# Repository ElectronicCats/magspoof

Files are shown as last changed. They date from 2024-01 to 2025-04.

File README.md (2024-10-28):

# MagSpoof By Electronic Cats
  
<a href="https://github.com/ElectronicCats/magspoof/wiki">
  <p align="center">
    
  </p>

<p align=center>
<a href="https://electroniccats.com/store/magspoof-v5/">
  
</a>
<a href="https://github.com/ElectronicCats/magspoof/wiki">
  
</a>
</p>

<p align=center>
Also available at distributors:
</p>
<p align=center>
<a href="https://labs.ksec.co.uk/product-category/electronic-cat/">

</a>
</p>

# What is MagSpoof?

**MagSpoof by Electronic Cats** is a device that can spoof/emulate any magnetic stripe or credit card. It can work "wirelessly", even on **standard magstripe/credit card readers**, by generating a strong electromagnetic field that emulates a traditional magnetic stripe card.

* Allows you to store all of your credit cards and magstripes in one device
* Works on traditional magstripe readers **wirelessly** (no NFC/RFID required)
* Can **disable** Chip-and-PIN (code not included)
* Correctly **predicts** Amex credit card numbers + expirations from previous card number (code not included)
* Supports all three magnetic stripe tracks, and even supports Track 1+2 simultaneously
* Easy to build using Arduino or other common parts

MagSpoof can be used as a traditional credit card and simply store all of your credit cards (and with modification, can technically disable chip requirements) in various impressive and exciting form factors, or can be used for security research in any area that would traditionally require a magstripe, such as readers for credit cards, drivers licenses, hotel room keys, automated parking lot tickets, etc.

**Note**: The Chip-and-PIN and Amex information is **not** implemented and using MagSpoof requires you to have/own the magstripes that you wish to emulate. Simply having a credit card number and expiration is not enough to perform transactions. MagSpoof **does** allow you to perform research in other areas of magstripes, microcontrollers, and electromagnetism, as well as learn about and create your own devices similar to other existing, commercial technologies such as <a href="http://www.samsung.com/us/support/answer/ANS00043865/997410383/">Samsung MST</a> and <a href="https://onlycoin.com/">Coin</a>.</p>

### ⚠️ Disclaimer ⚠️
MagSpoof is a wireless penetration testing tool intended solely for use in authorized security audits, where such usage is permitted by applicable laws and regulations. Before utilizing this tool, it is crucial to ensure compliance with all relevant legal requirements and obtain appropriate permissions from the relevant authorities.

It is essential to notice that the board does not provide any means or authorization to utilize credit cards or engage in any financial transactions that are not legally authorized. Electronic Cats holds no responsibility for any unauthorized use of the tool or any resulting damages.

-----

# Based in work of Samy Kamkar

**Point of Contact:** [@SamyKamkar](https://twitter.com/samykamkar)

You can see more of my projects at <http://samy.pl> or contact me at <code@samy.pl>.

------

## How to contribute 
 Contributions are welcome! 

Please read the document  [**Contribution Manual**](https://github.com/ElectronicCats/electroniccats-cla/blob/main/electroniccats-contribution-manual.md)  which will show you how to contribute your changes to the project.

✨ Thanks to all our [contributors](https://github.com/ElectronicCats/magspoof/graphs/contributors)! ✨

See  [**_Electronic Cats CLA_**](https://github.com/ElectronicCats/electroniccats-cla/blob/main/electroniccats-cla.md) for more information.

See the [**community code of conduct**](https://github.com/ElectronicCats/electroniccats-cla/blob/main/electroniccats-community-code-of-conduct.md)   for a vision of the community we want to build and what we expect from it.

### Maintainer

Electronic Cats invests time and resources in providing this open-source design design, please support Electronic Cats and open-source hardware by purchasing products from Electronic Cats!

<a href="https://github.com/sponsors/ElectronicCats">
  
</a>

# License

<a>
  
</a>

Electronic Cats invests time and resources in providing this open-source design. Please support Electronic Cats and open-source hardware by purchasing products from Electronic Cats!

Designed by Electronic Cats.

Firmware released under an GNU AGPL v3.0 license. See the LICENSE file for more information.

Hardware released under an CERN Open Hardware Licence v1.2. See the LICENSE_HARDWARE file for more information.

Electronic Cats is a registered trademark, please do not use if you sell these PCBs.

30 Octuber 2019

------

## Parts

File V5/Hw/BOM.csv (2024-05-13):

Reference | Value | Datasheet | Footprint | Qty | DNP | LCSC# | Proveedor | manf#
BT1 | Battery_Cell | ~ | Connector_PinHeader_2.54mm:PinHeader_1x02_P2.54mm_Vertical | 1 | DNP |  |  | -
C1,C2 | 0.1uF | https://datasheet.lcsc.com/lcsc/1810101813_YAGEO-CC0805KRX7R9BB104_C49678.pdf | Capacitor_SMD:C_0402_1005Metric | 2 |  | C2171572 | LCSC | GRM022R61A104ME01L
C3,C4,C17,C18 | 10uF | ~https://datasheet.lcsc.com/lcsc/1811021421_Samsung-Electro-Mechanics-CL10A106MP8NNNC_C85713.pdf | Capacitor_SMD:C_0402_1005Metric | 4 |  | C315248 | LCSC | CL05A106MP5NUNC
D1 | MBR120 | http://www.onsemi.com/pub_link/Collateral/MBR340-D.PDF | Diode_SMD:D_SOD-123F | 1 |  | C130880 | LCSC | MBR120LSF
D3 | Status | https://www.mouser.mx/datasheet/2/445/150080VS75000-1714385.pdf | LED_SMD:LED_0805_2012Metric_Pad1.15x1.40mm_HandSolder | 1 |  | C205442 | LCSC | 150080GS75000
D4 | CHG | https://www.mouser.mx/datasheet/2/445/150080RS75000-1714740.pdf | LED_SMD:LED_0805_2012Metric_Pad1.15x1.40mm_HandSolder | 1 |  | C130114 | LCSC | D-R080508L3-KS2
F1 | 0.5A | https://datasheet.lcsc.com/lcsc/1809211126_Shenzhen-JDT-Fuse-JFC0603-0500FS_C136327.pdf | Fuse:Fuse_0603_1608Metric | 1 |  | C2838887 | LCSC | 0603FA-R500
H1,H2,H3,H4 | MountingHole | ~ | MountingHole:MountingHole_2.2mm_M2_DIN965_Pad | 4 | DNP
J1 | SWD | ~ | Connector_PinHeader_2.54mm:PinHeader_1x04_P2.54mm_Vertical | 1 | DNP
J2 | SWD | ~ | Connector_PinHeader_2.54mm:PinHeader_1x04_P2.54mm_Vertical | 1 |  | C6332197 | LCSC | HB-PH3-25414PB2GOP
JP1 | boot | ~ | Connector_PinHeader_2.54mm:PinHeader_1x02_P2.54mm_Vertical | 1 |  | C492401 | LCSC | PZ254V-11-02P
L4 | 30t_30mm |  | magspoof:Coil_30t_30mm_0.2_0.2_0.6_0.3 | 1 | DNP
P1 | USB_C_Plug_USB2.0 | https://www.usb.org/sites/default/files/documents/usb_type-c.zip | magspoof:C393939 | 1 |  | C393939 | LCSC | TYPE-C16PIN
Q1 | DMG3415U-7 | https://www.mouser.mx/datasheet/2/115/ds31735-64958.pdf | Package_TO_SOT_SMD:SOT-23 | 1 |  | C96616 | LCSC | DMG3415UQ-7
R1 | 20K | https://www.mouser.mx/datasheet/2/54/cr-1858361.pdf | Resistor_SMD:R_0402_1005Metric | 1 |  | C2759509 | LCSC | ERJ-H2RD2002X
R2,R3,R9 | 5.1k | https://datasheet.lcsc.com/lcsc/1810170519_PANASONIC-ERJ3RBD5101V_C191782.pdf | Resistor_SMD:R_0402_1005Metric | 3 |  | C317922 | LCSC | AR02BTC5101
R7 | 180R | https://www.mouser.mx/datasheet/2/219/RK73B-1825463.pdf | Resistor_SMD:R_0402_1005Metric | 1 |  | C138045 | LCSC | ERJ-2RKF1800X
R10 | 470 | https://www.mouser.mx/datasheet/2/447/PYu_RC_Group_51_RoHS_L_11-1984063.pdf | Resistor_SMD:R_0402_1005Metric | 1 |  | C114877 | LCSC | RC0402FR-07470RL
R11 | 100K | https://datasheet.lcsc.com/lcsc/1811151133_Walsin-Tech-Corp-WR06X104JTL_C163843.pdf | Resistor_SMD:R_0402_1005Metric | 1 |  | C192169 | LCSC | ERJ-2RKF1003X
SW1 | ON | https://datasheet.lcsc.com/lcsc/1808041445_ALPSALPINE-SSSS811101_C109335.pdf | Library:SW-SMD_SSSS811101 | 1 |  | C109335 | LCSC | SSSS811101
SW3 | S1 | https://datasheet.lcsc.com/lcsc/2205161616_E-Switch-TL3342F450QG_C2886897.pdf | Button_Switch_SMD:SW_SPST_TL3342 | 1 |  | C318889 | LCSC | TL3342F450QG
SW4 | SOURCE MAG | https://datasheet.lcsc.com/lcsc/1808041445_ALPSALPINE-SSSS811101_C109335.pdf | Library:SW-SMD_SSSS811101 | 1 |  | C109335 | LCSC | SSSS811101
SW5 | RESET | https://www.mouser.mx/datasheet/2/140/TL3342-2065746.pdf | Button_Switch_SMD:SW_SPST_TL3342 | 1 |  | C318889 | LCSC | TL3342F450QG
U1 | CH552G | https://datasheet.lcsc.com/lcsc/2008191734_WCH-Jiangsu-Qin-Heng-CH552G_C111292.pdf | Package_SO:SOP-16_4.55x10.3mm_P1.27mm | 1 |  | C111292 | LCSC | CH552G
U2 | AP2112K-3.3 | https://www.diodes.com/assets/Datasheets/AP2112.pdf | Package_TO_SOT_SMD:SOT-23-5 | 1 |  | C47773 | LCSC | RT9013-33GB
U3 | TC4424 | https://www.mouser.mx/datasheet/2/268/21998b-53545.pdf | Package_SO:SOIC-8_3.9x4.9mm_P1.27mm | 1 |  | C44150 | LCSC | TC4424AVOA713
U5 | MCP73831 | http://ww1.microchip.com/downloads/en/DeviceDoc/20001984g.pdf | Package_TO_SOT_SMD:SOT-23-5 | 1 |  | C424093 | LCSC | MCP73831T-2ACI/OT

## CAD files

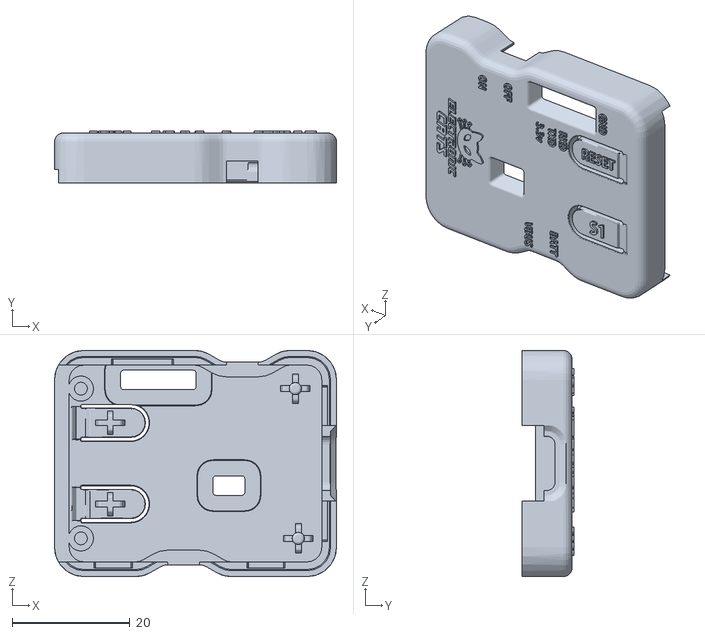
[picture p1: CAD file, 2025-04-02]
V5/Case/CS3-PART A-MAGSPOOF V5-CASE.stl
48.0 x 8.80 x 38.5

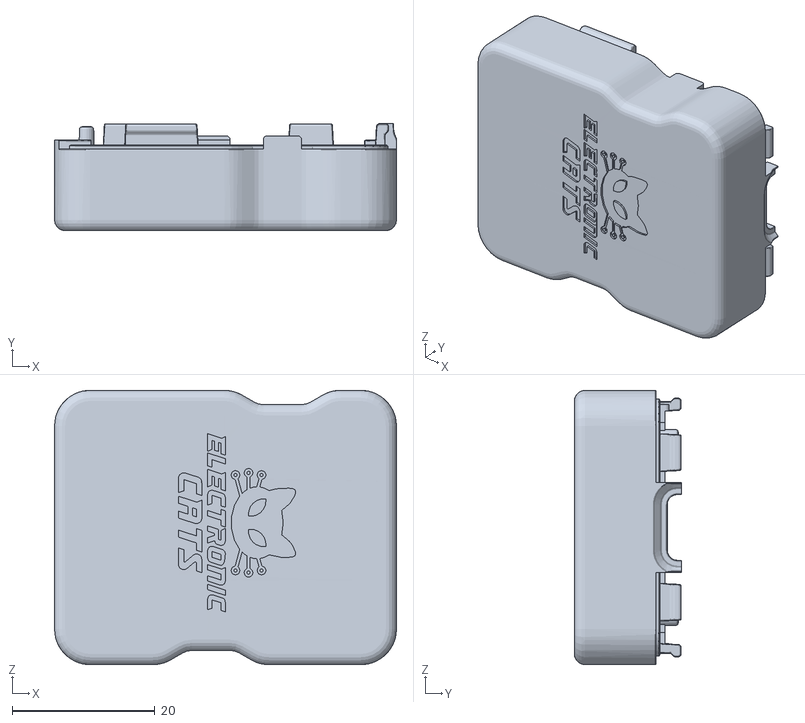
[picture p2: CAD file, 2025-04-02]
V5/Case/CS3-PART B-MAGSPOOF V5-CASE.stl
48.0 x 15.1 x 38.5

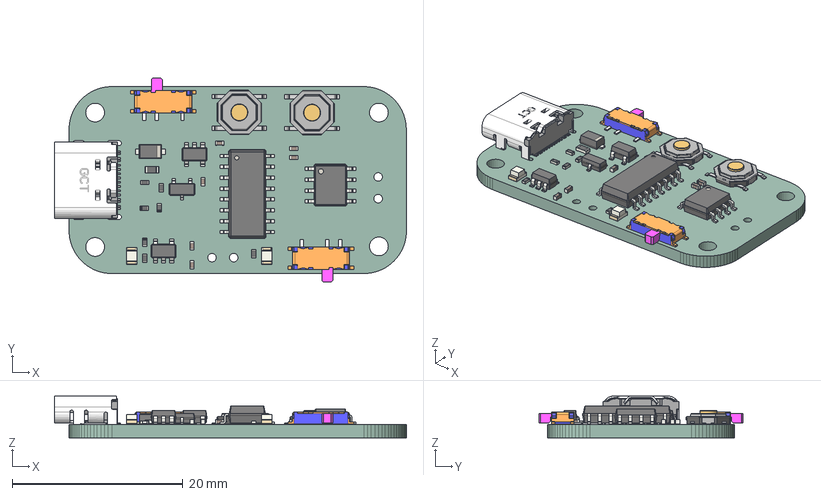
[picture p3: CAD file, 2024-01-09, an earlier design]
V4/Hw/Magspoof_V4.step
41.2 x 23.9 x 4.91 mm
_autosave-Magspoof_V4 PCB

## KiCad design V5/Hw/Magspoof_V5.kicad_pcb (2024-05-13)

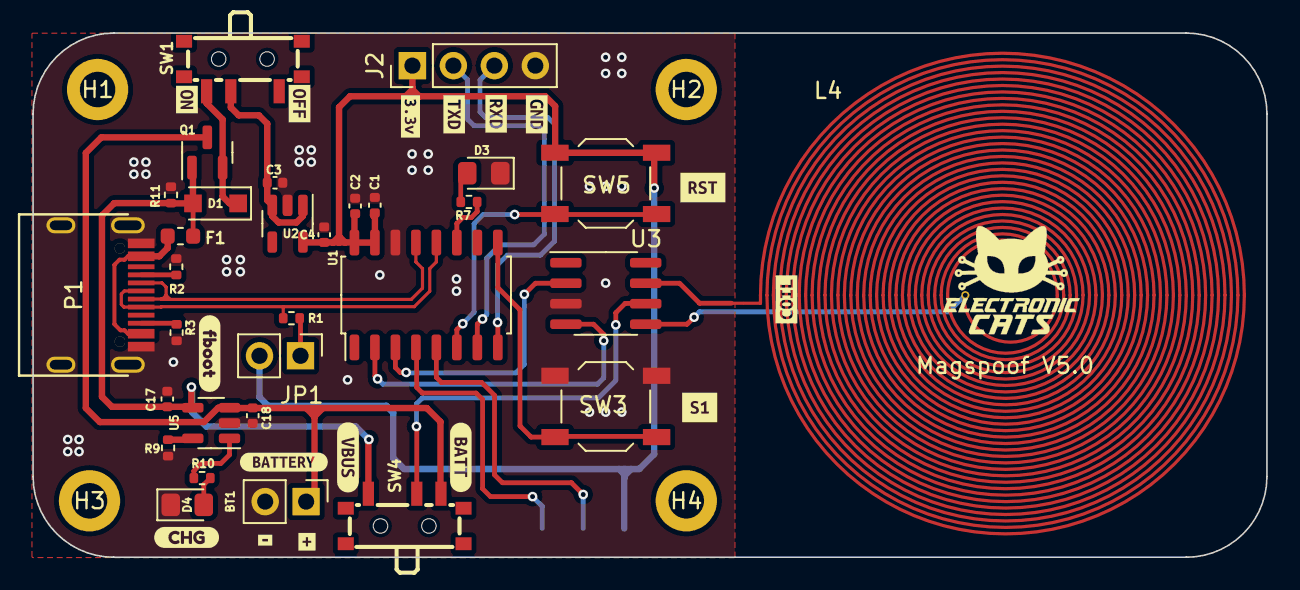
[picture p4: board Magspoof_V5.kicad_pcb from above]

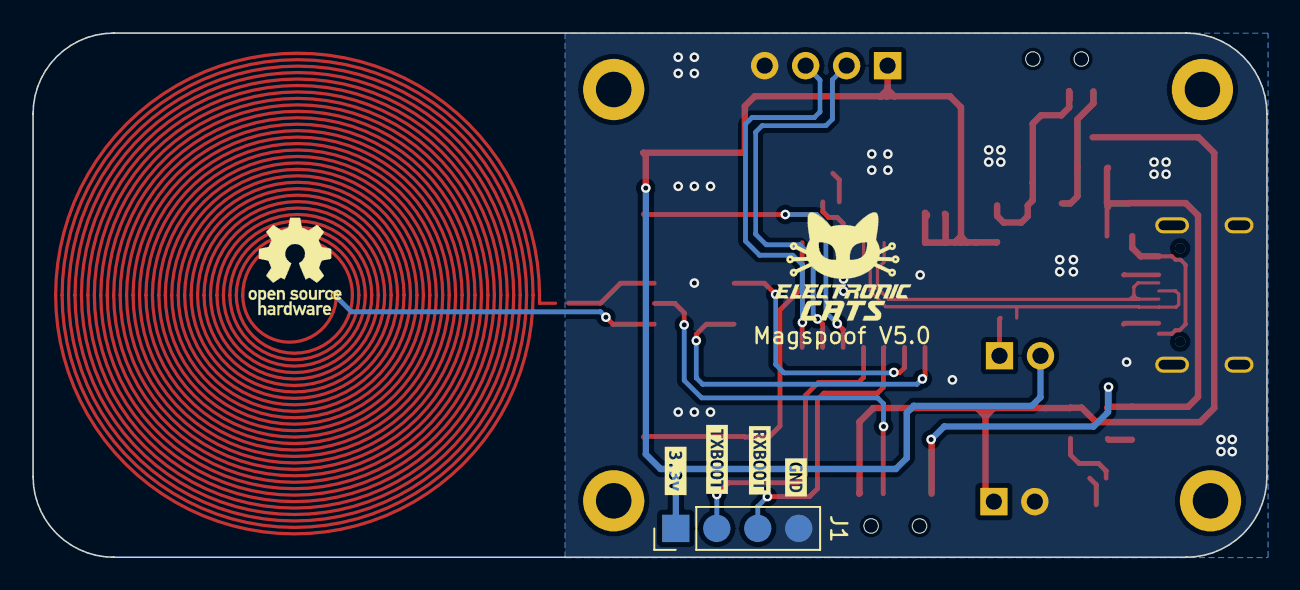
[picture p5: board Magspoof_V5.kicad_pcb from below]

Board: 2 copper layers, 76.5 x 32.5 mm, 56 parts (5 on the bottom side), 28 nets.

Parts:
BT1: Battery_Cell; PinHeader_1x02_P2.54mm_Vertical
C1, C2: 0.1uF; C_0402_1005Metric
C3, C4, C17, C18: 10uF; C_0402_1005Metric
D1: MBR120; D_SOD-123F
D3: Status; LED_0805_2012Metric_Pad1.15x1.40mm_HandSolder
D4: CHG; LED_0805_2012Metric_Pad1.15x1.40mm_HandSolder
F1: 0.5A; Fuse_0603_1608Metric
H1, H2, H3, H4: MountingHole; MountingHole_2.2mm_M2_DIN965_Pad
J1, J2: SWD; PinHeader_1x04_P2.54mm_Vertical
JP1: boot; PinHeader_1x02_P2.54mm_Vertical
L4: 30t_30mm; Coil_30t_30mm_0.2_0.2_0.6_0.3
P1: USB_C_Plug_USB2.0; C393939
Q1: DMG3415U-7; SOT-23
R1: 20K; R_0402_1005Metric
R2, R3, R9: 5.1k; R_0402_1005Metric
R7: 180R; R_0402_1005Metric
R10: 470; R_0402_1005Metric
R11: 100K; R_0402_1005Metric
SW1: ON; SW-SMD_SSSS811101
SW3: S1; SW_SPST_TL3342
SW4: SOURCE MAG; SW-SMD_SSSS811101
SW5: RESET; SW_SPST_TL3342
U1: CH552G; SOP-16_4.55x10.3mm_P1.27mm
U2: AP2112K-3.3; SOT-23-5
U3: TC4424; SOIC-8_3.9x4.9mm_P1.27mm
U5: MCP73831; SOT-23-5
kibuzzard-660F1CC0: G***; kibuzzard-660F1CC0
kibuzzard-660F1CCE: G***; kibuzzard-660F1CCE
kibuzzard-6435F1C7: G***; kibuzzard-6435F1C7
kibuzzard-6435F3C4: G***; kibuzzard-6435F3C4
kibuzzard-6436E8D1: G***; kibuzzard-6436E8D1
kibuzzard-6436E8D8: G***; kibuzzard-6436E8D8
kibuzzard-6436EA37: G***; kibuzzard-6436EA37
kibuzzard-6436EA46: G***; kibuzzard-6436EA46
kibuzzard-6436EF9F: G***; kibuzzard-6436EF9F
kibuzzard-6436EF98: G***; kibuzzard-6436EF98
kibuzzard-6616D9B1: G***; kibuzzard-6616D9B1
kibuzzard-6616D9C5: G***; kibuzzard-6616D9C5
kibuzzard-6616D9E2: G***; kibuzzard-6616D9E2
kibuzzard-6616D983: G***; kibuzzard-6616D983
kibuzzard-6616DB9C: G***; kibuzzard-6616DB9C
kibuzzard-6616DCE6: G***; kibuzzard-6616DCE6
kibuzzard-64629FC5: G***; kibuzzard-64629FC5
kibuzzard-64629FDC: G***; kibuzzard-64629FDC
kibuzzard-64665C6A: G***; kibuzzard-64665C6A
kibuzzard-64665C9F: G***; kibuzzard-64665C9F

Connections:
+3V3: C1.1, C2.1, C4.1, J1.1, J2.1, JP1.2 (B), SW5.2, U1.15 (VCC), U1.16 (V33), U2.5 (VOUT)
+BATT: BT1.1 (+), C18.1, Q1.3 (D), SW4.3 (C), U5.3 (VBAT)
/D+: P1.A6 (D+), R1.2, U1.12 (P3.6)
/D-: P1.A7 (D-), U1.13 (P3.7)
/IN_A: U1.2 (P1.4), U3.4 (IN_B)
/IN_B: U1.3 (P1.5), U3.2 (IN_A)
/LED: R7.1, U1.11 (P3.4)
/Out_A: L4.1, U3.7 (OUT_A)
/Out_B: L4.2, U3.5 (OUT_B)
/RST: SW5.1, U1.6 (RST)
/RXD: J2.3, U1.8 (P3.0)
/RXD_BOOT: J1.3, U1.4 (P1.6)
/SW1: SW3.2, U1.9 (P1.1)
/TXD: J2.2, U1.7 (P3.1)
/TXD_BOOT: J1.2, U1.5 (P1.7)
GND: BT1.2 (-), C1.2, C2.2, C3.2, C4.2, C17.2, C18.2, D3.1 (K), D4.1 (K), J1.4, J2.4, P1.A1 (GND), P1.S1 (SHIELD), R2.1, R3.1, R9.2, R11.2, SW3.1, U1.14 (GND), U2.2 (GND), U3.3 (GND), U5.2 (VSS)
unnamed: D1.1 (K), Q1.2 (S), SW1.3 (A)
unnamed: D3.2 (A), R7.2
unnamed: D4.2 (A), R10.2
unnamed: F1.1, P1.A4 (VBUS)
unnamed: JP1.1 (A), R1.1
unnamed: P1.A5 (CC), R2.2
unnamed: P1.B5 (VCONN), R3.2
unnamed: C3.1, SW1.2 (B), U2.1 (VIN), U2.3 (EN)
unnamed: SW4.2 (B), U3.6 (VDD)
unnamed: R9.1, U5.5 (PROG)
unnamed: R10.1, U5.1 (STAT)
VBUS: C17.1, D1.2 (A), F1.2, Q1.1 (G), R11.1, SW4.1 (A), U5.4 (VDD)

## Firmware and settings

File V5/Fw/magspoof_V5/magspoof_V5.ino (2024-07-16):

/************************************************************
  Magspoof V5
  Modified version by Eduardo Contreras
  for Electronic Cats

  Original code by Samy Kamkar (http://samy.pl/magspoof/)

  This example demonstrates how to use Magspoof v3 by Electronic Cats
  https://github.com/ElectronicCats/magspoof

  Development environment specifics:
  IDE: Arduino 1.8.9
  Hardware Platform:
  Magspoof V4

  This code is beerware; if you see me (or any other Electronic Cats
  member) at the local, and you've found our code helpful,
  please buy us a round!
  Distributed as-is; no warranty is given.
*/


#define PINS_PORT 1
#define PIN_A_BIT 4
#define PIN_B_BIT 5

#define BUTTON_PIN 11      // Button pin number
#define LED 34             // LED pin number
#define CLOCK_US 200       // Clock pulse duration in microseconds

#define BETWEEN_ZERO 53 // 53 zeros between track1 & 2

#define TRACKS 2           // Number of magnetic tracks emulated
#define MAX 80             // Maximum length of each track

//This is a fairly large array, store it in external memory with keyword __xdata
__xdata char recvStr[MAX];
uint8_t recvStrPtr = 0;
bool stringComplete = false;
bool serialComplete = false;
uint16_t echoCounter = 0;

// tracks in RAM
char tracks[2][MAX] = {
  "%B123456781234567^LASTNAME/FIRST^YYMMSSSDDDDDDDDDDDDDDDDDDDDDDDDD?\0", // Track 1
  ";123456781234567=112220100000000000000?\0" // Track 2
};

char revTrack[41]; // Array to store reversed track data

int sublen[] = {
  32, 48, 48
};

int bitlen[] = {
  7, 5, 5
};

unsigned int curTrack = 0;
uint8_t dir;

// Function to blink an LED on a specific pin
void blink(uint8_t pin, int msdelay, int times) {
  for (uint8_t i = 0; i < times; i++) {
    digitalWrite(pin, HIGH);
    delay(msdelay);
    digitalWrite(pin, LOW);
    delay(msdelay);
  }
}

void showEEPROM() {
  
USBSerial_println("EEPROM track 1:");

  for (uint8_t i = 0; i < MAX; i++) {
    char eepromData = eeprom_read_byte(i);
    tracks[0][i] = eepromData;
    USBSerial_print(tracks[0][i]);
    if (tracks[0][i] == '?') {
      tracks[0][i + 1] = '\0';
      break;
    }
  }

  //load track2 from eeprom
  USBSerial_println();
  USBSerial_println("EEPROM track 2:");
  
  for (uint8_t i = MAX; i < 2 * MAX; i++) {
    char eepromData = eeprom_read_byte(i);
    tracks[1][i - MAX] = eepromData;
    USBSerial_print(tracks[1][i - MAX]);
    if (tracks[1][i - MAX] == '?') {
      tracks[1][i + 1 - MAX] = '\0';
      break;
    }
  }
}

// send a single bit out
void playBit(int sendBit) {
  dir ^= 1;
  digitalWriteFast(PINS_PORT, PIN_A_BIT, dir);
  digitalWriteFast(PINS_PORT, PIN_B_BIT, !dir);
  delayMicroseconds(CLOCK_US);

  if (sendBit) {
    dir ^= 1;
    digitalWriteFast(PINS_PORT, PIN_A_BIT, dir);
    digitalWriteFast(PINS_PORT, PIN_B_BIT, !dir);
  }
  delayMicroseconds(CLOCK_US);

}

// when reversing
void reverseTrack(int track) {
  int i = 0;
  track--; // index 0
  dir = 0;

  while (revTrack[i++] != '\0');
  i--;
  while (i--)
    for (int j = bitlen[track] - 1; j >= 0; j--)
      playBit((revTrack[i] >> j) & 1);
}

// plays out a full track, calculating CRCs and LRC
void playTrack(int track) {
  int tmp, crc, lrc = 0;
  track--; // index 0
  dir = 0;

  // First put out a bunch of leading zeros.
  for (int i = 0; i < 25; i++)
    playBit(0);

  //
  for (int i = 0; tracks[track][i] != '\0'; i++)
  {
    crc = 1;
    tmp = tracks[track][i] - sublen[track];

    for (int j = 0; j < bitlen[track] - 1; j++)
    {
      crc ^= tmp & 1;
      lrc ^= (tmp & 1) << j;
      
      playBit(tmp & 1);
      tmp >>= 1;
    }
    playBit(crc);
  }
  
  // finish calculating and send last "byte" (LRC)
  tmp = lrc;
  crc = 1;
  
  for (int j = 0; j < bitlen[track] - 1; j++)
  {
    crc ^= tmp & 1;
    playBit(tmp & 1);
    tmp >>= 1;
  }
  playBit(crc);

  // if track 1, play 2nd track in reverse (like swiping back?)
  if (track == 0)
  {
    // if track 1, also play track 2 in reverse
    // zeros in between
    for (int i = 0; i < BETWEEN_ZERO; i++)
      playBit(0);

    // send second track in reverse
    reverseTrack(2);
  }

  // finish with 0's
  for (int i = 0; i < 5 * 5; i++)
    playBit(0);

  digitalWriteFast(PINS_PORT, PIN_A_BIT, LOW);
  digitalWriteFast(PINS_PORT, PIN_B_BIT, LOW);
}

// stores track for reverse usage later
void storeRevTrack(int track) {
  int i, tmp, crc, lrc = 0;
  track--; // index 0
  dir = 0;

  for (i = 0; tracks[track][i] != '\0'; i++)
  {
    crc = 1;
    tmp = tracks[track][i] - sublen[track];

    for (int j = 0; j < bitlen[track] - 1; j++)
    {
      crc ^= tmp & 1;
      lrc ^= (tmp & 1) << j;
      tmp & 1 ?
      (revTrack[i] |= 1 << j) :
      (revTrack[i] &= ~(1 << j));
      tmp >>= 1;
    }
    crc ?
    (revTrack[i] |= 1 << 4) :
    (revTrack[i] &= ~(1 << 4));
  }


  // finish calculating and send last "byte" (LRC)
  tmp = lrc;
  crc = 1;
  for (int j = 0; j < bitlen[track] - 1; j++)
  {
    crc ^= tmp & 1;
    tmp & 1 ?
    (revTrack[i] |= 1 << j) :
    (revTrack[i] &= ~(1 << j));
    tmp >>= 1;
  }
  crc ?
  (revTrack[i] |= 1 << 4) :
  (revTrack[i] &= ~(1 << 4));

  i++;
  revTrack[i] = '\0';
}

void s_print(char *s) {
  for (int i = 0; i < MAX ; i++) {
    USBSerial_print(s[i]);
    if (s[i] == '?')break;
  }
  USBSerial_println();
}

// Alternative function to control the operation based on input option
void play(int option){
  digitalWrite(LED, HIGH);

  switch(option){
  case 1:
    // Play track 1
    playTrack(1);
    digitalWrite(LED, LOW);
    USBSerial_println("MagSpoof activated");
    break;
  case 2:
    // Play track 2
    playTrack(2);
    digitalWrite(LED, LOW);
    USBSerial_println("MagSpoof activated");
    break;
  case 0:
    // Play alternating tracks on successive button presses
    playTrack(1 + (curTrack++ % 2));
    digitalWrite(LED, LOW);
    USBSerial_println("MagSpoof activated");
  }
}

// Setup function to initialize hardware and load data
void setup() {
  Serial0_begin(9600);

  delay(2000);
  
  pinMode(LED, OUTPUT);
  digitalWrite(LED, LOW);

  pinModeFast(PINS_PORT, PIN_A_BIT, OUTPUT);
  pinModeFast(PINS_PORT, PIN_B_BIT, OUTPUT);
  pinMode(BUTTON_PIN, INPUT_PULLUP);

  storeRevTrack(TRACKS);

  USBSerial_println();
  USBSerial_flush();
  USBSerial_println("MAGSPOOF");
  USBSerial_println();
  USBSerial_println("h: Help");
  USBSerial_println();
}

// Main loop to handle button presses and USB serial commands
void loop() {
  if (digitalRead(BUTTON_PIN) == 0) {
    USBSerial_println("MagSpoof");
    digitalWrite(LED, HIGH);
    play(0);
    digitalWrite(LED, LOW);
    s_print(tracks[0]);
    s_print(tracks[1]);
  }
  
  // Handle incoming serial data
  while (Serial0_available()) {
    char serialChar = Serial0_read();
    USBSerial_write(serialChar);
    if ((serialChar == '\n') || (serialChar == '\r') ) {
      recvStr[recvStrPtr] = '\0';
      if (recvStrPtr > 0) {
        serialComplete = true;
        break;
      }
    } else {
      recvStr[recvStrPtr] = serialChar;
      recvStrPtr++;
      if (recvStrPtr == MAX) {
        recvStr[recvStrPtr] = '\0';
        digitalWrite(LED, HIGH);
        delay(50);
        digitalWrite(LED, LOW);
        serialComplete = true;
        break;
      }
    }
  }

  while (USBSerial_available()) {
    char serialChar = USBSerial_read();
    if ((serialChar == '\n') || (serialChar == '\r') ) {
      recvStr[recvStrPtr] = '\0';
      if (recvStrPtr > 0) {
        stringComplete = true;
        break;
      }
    } else {
      recvStr[recvStrPtr] = serialChar;
      recvStrPtr++;
      if (recvStrPtr == MAX) {
        recvStr[recvStrPtr] = '\0';
        stringComplete = true;
        break;
      }
    }
  }
  
  // Process complete strings from USB serial
  if (stringComplete || serialComplete) {

  // Store tracks in EEPROM
    if (recvStr[0] == 's') {

      USBSerial_println("...to EEPROM");
      for (uint8_t i = 0; i < MAX ; i++) {
        eeprom_write_byte(i, tracks[0][i]);
        if (tracks[0][i] == '?') {
          eeprom_write_byte(i + 1, '\0');
          tracks[0][i + 1] = '\0';
          break;
        }
      }

      for (uint8_t i = MAX; i < 2 * MAX ; i++) {
        eeprom_write_byte(i, tracks[1][i - MAX]);
        if (tracks[1][i] == '?') {
          eeprom_write_byte(i + 1, '\0');
          tracks[1][i + 1] = '\0';
          break;
        }
      }
      
      serialComplete = false;
      stringComplete = false;
      USBSerial_flush();  
    }

    if (recvStr[0] == '%') {
      for (uint8_t i = 0; i < MAX ; i++) {
        tracks[0][i] = recvStr[i];
        if (recvStr[i] == '?') {
          {
            tracks[0][i + 1] = '\0';
            break;
          }
        }
      }
      storeRevTrack(TRACKS);
    }

    if (recvStr[0] == ';') {
      for (uint8_t i = 0; i < MAX ; i++) {
        tracks[1][i] = recvStr[i];
        if (recvStr[i] == '?') {
          {
            tracks[1][i + 1] = '\0';
            break;
          }
        }
      }
      storeRevTrack(TRACKS);
    }

    // Play tracks in RAM
    if (recvStr[0] == 'p') {
      if(recvStr[1] == '1') {
      USBSerial_println();  
      USBSerial_print("PLAY TRACK 1");
      USBSerial_println();
      play(1);  
      }
      else if(recvStr[1] == '2') {
      USBSerial_println();  
      USBSerial_print("PLAY TRACK 2");
      USBSerial_println();
      play(2);   
      }
      else {
      USBSerial_println();  
      USBSerial_print("PLAY");
      USBSerial_println();
      play(0);
      }  
    }

  // Print tracks stored in RAM
  if (recvStr[0] == 'd') {   
    USBSerial_println();
    USBSerial_println("RAM TRACK 1:");
    s_print(tracks[0]);
    USBSerial_println("RAM TRACK 2:");
    s_print(tracks[1]);
    USBSerial_println();  
  }

    // Print tracks stored in RAM
  if (recvStr[0] == 'l') {   
    showEEPROM(); 
  }

    // Print tracks stored in RAM
  if (recvStr[0] == 'e') {
    showEEPROM();
    USBSerial_println();  
  }

  // Print help menu
  if (recvStr[0] == 'h') {
    USBSerial_println();
    USBSerial_println("Available commands:");
    USBSerial_println("h: Help (display this menu)");
    USBSerial_println("s: Save tracks from RAM to EEPROM");
    USBSerial_println("p1: Play track 1");
    USBSerial_println("p2: Play track 2");
    USBSerial_println("p: Play tracks alternating between 1 and 2");
    USBSerial_println("l: Load the contents of tracks in EEPROM");
    USBSerial_println("d: Display the contents of tracks in RAM");
    USBSerial_println("e: Display the contents of tracks in EEPROM");
    USBSerial_println();
  }

  recvStrPtr = 0;
  serialComplete = false;
  stringComplete = false;
  USBSerial_flush();  
  
 }
}

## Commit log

2023-12-20 Update README.md
    Changes:
    1.- Adding pictures of the device to the presentation and wiki section
    2.- Adding pictures with links to the store and wiki
2023-12-20 Update README.md
    1.- Adding pictures of the device to the general description and wiki section.
    2.- Adding links to the store and the wiki
    3.- Adding picture for the license
    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
2023-12-21 Update README.md
    Changes in the button to the store
2024-03-05 feat: flat spiral coil proposals for PCB antenna
    [Magspoof_V4.kicad_pcb, Magspoof_V4.kicad_sch]
2024-03-11 feat(hw): add 2 additional coils and the specs of the coils
    [Magspoof_V4.kicad_pcb, Magspoof_V4.kicad_sch]
2024-03-20 feat(hw): add Test coils panel
    [Test Coils.kicad_pcb, Test Coils.kicad_sch]
2024-03-20 fix(hw): route correction
    [Test Coils.kicad_pcb]
2024-03-20 feat(hw): panelizing
    [Test Coils.kicad_pcb]
2024-03-21 fix(hw): change edge cuts
    [Test Coils.kicad_pcb]
2024-03-21 fix(hw): update edge cuts
    [Test Coils.kicad_pcb]
2024-03-22 fix(hw): panelization changes
    [Test Coils.kicad_pcb]
2024-04-04 feat(hw): Magspoof V5 pcb and layaout added
    [Magspoof_V5.kicad_pcb, Magspoof_V5.kicad_sch]
2024-04-08 feat(hw): components got reorganized
    [Magspoof_V5.kicad_pcb, Magspoof_V5.kicad_sch]
2024-04-08 feat(hw): TX and RX pins updated
    [Magspoof_V5.kicad_pcb, Magspoof_V5.kicad_sch]
2024-04-08 feat(hw): path width changed
    [Magspoof_V5.kicad_pcb]
2024-04-09 fix(hw): Some paths got corrections
    [Magspoof_V5.kicad_pcb]
2024-04-09 fix(hw): pins Serial boot
    [Magspoof_V5.kicad_sch]
2024-04-09 feat(hw): add logos
    [Magspoof_V5.kicad_pcb]
2024-04-10 feat(hw): added TX and RX Boot pins
    [Magspoof_V5.kicad_pcb, Magspoof_V5.kicad_sch]
2024-04-10 feat(hw): logos
    [Magspoof_V5.kicad_pcb]
2024-04-11 feat(hw): components organization updated
    [Magspoof_V5.kicad_pcb]
2024-04-11 feat(hw): BOM generated
    [BOM.csv, Magspoof_V5.kicad_sch]
2024-04-11 fix(hw): orientation logo
    [Magspoof_V5.kicad_pcb]
2024-04-11 feat(hw): move label batt
    [Magspoof_V5.kicad_pcb]
2024-04-11 feat(hw): BOM got updated
    [BOM.csv, Magspoof_V5.kicad_pcb, Magspoof_V5.kicad_sch]
2024-04-11 feat(hw): USB manufacture part updated
    [BOM.csv, Magspoof_V5.kicad_sch]
2024-04-11 fix(hw): layer correction of dimension comments
    [Magspoof_V5.kicad_pcb]
2024-04-24 feat(docs): add distributor button
2024-04-24 feat(docs): add text and distributor button
2024-06-26 fix(hw): DNP update of the list components
    [Magspoof_V5.kicad_sch]
2024-07-01 fix(hw): change path test coils
    [Test Coils.kicad_pcb, Test Coils.kicad_sch]
2024-07-01 fix: remove code comments
    [magspoof_V5.ino]
2024-07-02 fix: NL and CR ok
    [magspoof_V5.ino]
2025-04-02 feat(hw); add STL case files
    [CS3-PART A-MAGSPOOF V5-CASE.stl, CS3-PART B-MAGSPOOF V5-CASE.stl]
